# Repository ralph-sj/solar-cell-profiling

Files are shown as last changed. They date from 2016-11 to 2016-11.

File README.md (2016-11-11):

# solar-cell-profiling using a low power micro-computer
Hardware and software for power profiling a solar cell over a range of irradiances using cheap/easy to use hardware and software e.g. low power ADC/op-amps and raspberry pi/arduino 

## Introduction

A raspberry pi can be set up to measure voltages over time as a simple datalogger.  An ADC is connected to the IO pins of the pi and configured to take measurements and return the data to the Pi.  Data can then be sent to a remote server or stored locally or processed further.

## Guides
Mathworks [1] have a simple tutorial for setting this up with an LCD screen.	This uses the MCP3004 ADC [2] connected to the raspberry pi.

## Impedance
The input impedance of the ADC determines the current sunk by the ADC from the source which it is measuring.  When the input impedance is low compared to the output impedance of the source then there will be a voltage drop due to the ADC sinking current.  There are guides that show examples of this and address ways to counter it [3,4].	

## Hardware

The hardware used here is selected for ease of use and availability, including the procesor, sensors and other peripherals. It consists of: 
- MSP430G2553 Launchpad.  This is the demo board for the G2553 variant of the popular MSP430 MCU.
- LT1920 instrumentation amplifier.

### MCU
### Trans-Impedance Amplifier
This is used decrease the voltage drop imposed by the use of an ammeter in series within the monitoring circuit.  This allows a 1 Ohmm resistor to be used rather than the higher burden 1k.  As the currents measured here are typically low (uA - mA), to e.g. resolve a 1uA current without gain (i.e. to convert a 1uA current to 1mA - the maximum resolution of the 10-bit ADC used with a 1V reference) a 1K resistor would be needed.  This would then drop the voltage in the circuit by that amount.  By using a 1 Ohm resistor, that burden is reduced to an almost immeasurable 1 uA ^[11].  The burden voltage is 10µV/µA and 10µV/nA on the lower ranges and varies on the mA range due to the switch resistance.  

**Ranges:**

- Current ranges:
    1. +/- 0-300mA (70µV / mA burden voltage typical) - max 21mV
    2. +/- 0-1000µA (10µV / uA burden voltage) - max 10 mV
    3. +/- 0-1000nA (10µV / nA burden voltage) - max 10 mV
- Output Voltage Units:
    1. 1mV/mA - max 3V
    2. 1mV/µA - max 1V
    3. 1mV/nA - max 1V
- Effective gain 100 (I think)

### Instrumentation amplifier
The **LT2910** instrumentation amplifier is used to amplify the signal from the trans-impedance amplifier.  The gain is variable from 1 to 10,00 and is determined by the value of the gain resistor, RG, connected across pins 1-8.  The gain for a given value of RG is given by
G = 1 + 49.4/RG
i.e. for the following gain values:
Gain = 1000, RG = 49.4 Ohms
Gain = 100, RG = 499 Ohms
Gain = 10, RG = 5.489 kOhms

An alternative is the AD8428 ^[6] which has a fixed gain of 2000

## Software
Simpel software running on a low power procesosr is to be created to read sensors and then save data in a remote server. It is designed to run on  the MSP-EXP430G2 launchpad ^[7],[8],[10].  This is used due to their availability, ease of use and low power operation
 
### Development environment
The Arduino-like Energia ^[9] development environment was used here due to the ease of use and the widespread availability of libraries.

## References
[1](http://makerzone.mathworks.com/resources/build-a-digital-voltmeter-using-raspberry-pi/) Mathworks, "Build a Digital Voltmeter Using Raspberry Pi" (2005)
[2](https://cdn-shop.adafruit.com/datasheets/MCP3008.pdf), Microchip, MCP3004 Datasheet (2008)
[3](http://www.ti.com/lit/an/spna088/spna088.pdf)
[4](http://www.ti.com/lit/an/sbaa090/sbaa090.pdf)
[5](http://cds.linear.com/docs/en/datasheet/1920f.pdf), LT21920 Datasheet
[6](http://www.analog.com/media/en/technical-documentation/data-sheets/AD8428.PDF), AD8428
[7](http://www.ti.com/tool/MSP-EXP430G2), MSP-EXP430G2 homepage
[9](http://energia.nu/pin-maps/guide_msp430g2launchpad/), Energia for launchpad
[10](http://www.ti.com/lsds/ti/tools-software/launchpads/launchpads.page), TI Launchpad Homepage
[11](http://alternatezone.com/electronics/ucurrent/uCurrentArticle.pdf), uCurrent infor sheet

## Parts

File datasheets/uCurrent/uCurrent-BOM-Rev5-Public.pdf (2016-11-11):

ITEM # | Designator | Part Number | Manufacturer | Description | Supplier 1 | Supplier 1 Part#
1 U1, U4 | MAX4239AUT | Maxim | MAX4239AUT+T OPAMP SOT23-6 | MAX4239AUT+T-ND | 2
2 U2 | LMV321AS5X | TI | 296-9567-1-ND | 1
3 U3 | TI | Voltage Monitor 3.0V/2.7V, Active Low | 1
4 R1 | Y14870R01000B9R | Resistor 0.01ohm 0.1% 15ppm 2512 package | Y14870R01000B9R | 1
5 R5, R15 | 1K 0.05% 0603 10ppm | 2
6 R3, R13 | RG1608N-682-W-T1 | 6K8 0.05% 0603 10ppm | RG16N6.8KWTR-ND | 2
7 R11, R14 | 2K2 0.05% 0603 10ppm | RG16N2.2KWTR-ND | 2
8 R2 | RG1608N-103-W-T1 | 10K 0.05% 0603 10ppm | RG16N10.0KWTR-ND | 1
9 R9 | RNCF0805AKT10R0 | 10R 0.05% 0805 10ppm | RNCF0805AKT10R0-ND | 1
10 R6, R7 | Any | 100K 1% 0603 | 2
11 R4, R8,R10,R12 | Any | 270R 1% 0603 | 4
12 C1, C2 | Any | 100nF 0603 X7R Capacitor | 2
13 C3, C4 | Any | 10pF 0603 X7R capacitor | 2
14 SW1, SW2 | C&K | CKC5111-ND | 2
15 BT1 | 1060K | Keystone | 2032 Battery Holder SMD | 1060K-ND | 1
16 D1 | APTR3216SYCK | 1206 Reverse Mount Orange LED | 754-1174-2-ND | 1
17 | UB5 | UB5 Jiffy Box | H0205 | 1
19 | Black Binding Post 12mm Gold on Copper | 99cent Hobbies | 16-010 (306-H) | 2
20 | Red Binding Post 12mm Gold on Copper | 99cent Hobbies | 16-010 (306-H) | 2

uCurrent Rev 5 Parts List

Qty

Digikey
SOT23-5 Opamp | Digikey
TPS3809L30DBVR (http://www.digikey.com/product-detail/en/TPS3809L30DBVR/296-10917-2-ND/382242) | | Digikey | 296-10917-2-ND
| Vishay | Digikey
RG1608N-102-W-T1 (http://www.digikey.com/product-detail/en/RG1608N-102-W-T1/RG16N1.0KWTR-ND/600597) | Susumu | Digikey | RG16N1.0KWTR-ND
| Susumu (http://digikey.com/Suppliers/us/Susumu.page?lang=en) | Digikey
RG1608N-222-W-T1 (http://www.digikey.com/product-detail/en/RG1608N-222-W-T1/RG16N2.2KWTR-ND/600605) | Susumu | Digikey
| Susumu | Digikey
| Stackpole (http://digikey.com/Suppliers/us/Stackpole-Electronics.page?lang=en) | Digikey
| | Digikey
| | Digikey
| | Digikey
| | Digikey | 1276-2154-2-nd
L203011MS02Q or
L203011MS02QE

SW SLIDE DP3T 6VDC 4A PCB NO
COMMON | Digikey
| | Digikey
| Kingbright | Digikey
| Altronics | Altronics

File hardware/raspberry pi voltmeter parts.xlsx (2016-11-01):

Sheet: Sheet1
Part | type | more info | size | purpose | No. required | Price | supplier link | Supplier order code | Mnfctr | Mnfctr. part no. | Net cost | Homepage | Datasheet | Note | Order note
ADC | ADC with Integrated Oscillator, and Reference | 4 channel | 12 bit | solar cell IV monitoring | 5 | 1.88 | ebay (China) (http://www.ebay.co.uk/itm/ADS1015-12-bit-precision-analog-to-digital-converter-ADC-development-board-/191891529986) | - | TI | ADS1015 | 9.4 | http://www.ti.com/product/ads1015 | http://www.ti.com/lit/ds/symlink/ads1013.pdf | on board | Ordered 01/11/2016
ADC | ADC with Integrated Oscillator, and Reference | 4 channel | 16 bit | solar cell IV monitoring | 5 | 1.97 | ebay (China) (http://www.ebay.co.uk/itm/16Bit-I2C-ADS1115-Module-ADC-4-channel-Pro-Gain-Amplifier-for-Arduino-RPi-/272041590206) | - | TI | ADS1115 | 9.85 | http://www.ti.com/product/ads1115/description | http://www.ti.com/lit/ds/symlink/ads1115.pdf | on board | Ordered 01/11/2016
ADC | ADC with Integrated Oscillator, and Reference | 1 channel | 12 bit | solar cell IV monitoring | 5 |  | ebay (China) | - | TI | ADS1013 | 0 | http://www.ti.com/product/ads1013 | http://www.ti.com/lit/ds/symlink/ads1013.pdf | on board
ADC | ADC with Integrated Oscillator, and Reference | 1 channel | 16 bit | solar cell IV monitoring | 5 |  | ebay (China) | - | TI | ADS1113 | 0 | http://www.ti.com/product/ads1113 | http://www.ti.com/lit/ds/symlink/ads1115.pdf | on board
ADC | ADC with Integrated Oscillator, and Reference | 4 channel | 12 bit | solar cell IV monitoring | 1 |  | ebay (UK) | - | TI | ADS1015 | 0 | http://www.ti.com/product/ads1016 | http://www.ti.com/lit/ds/symlink/ads1013.pdf | on board
ADC | ADC with Integrated Oscillator, and Reference | 4 channel | 16 bit | solar cell IV monitoring | 1 | £4.59 | ebay (UK) (http://www.ebay.co.uk/itm/16-Bit-I2C-Analogue-to-Digital-Convertor-Pro-Gain-Amp-ADS1115-4-Ch-Flux-Workshop-/111833735071) | - | TI | ADS1115 | 4.59 | http://www.ti.com/product/ads1115/description | http://www.ti.com/lit/ds/symlink/ads1115.pdf | on board | Ordered 01/11/2016
ADC | ADC with Integrated Oscillator, and Reference | 1 channel | 12 bit | solar cell IV monitoring | 1 |  | ebay (UK) |  | TI | ADS1013 | 0 | http://www.ti.com/product/ads1213 | http://www.ti.com/lit/ds/symlink/ads1013.pdf | on board
ADC | ADC with Integrated Oscillator, and Reference | 1 channel | 16 bit | solar cell IV monitoring | 1 |  | ebay (UK) |  | TI | ADS1113 | 0 | http://www.ti.com/product/ads1313 | http://www.ti.com/lit/ds/symlink/ads1115.pdf | on board
ADC | ADC with Integrated Oscillator, and Reference | 4 channel | 12 bit | solar cell IV monitoring | 20 | 1.99 | farnell (http://uk.farnell.com/texas-instruments/ads1015idgst/adc-12bit-i2c-int-mux-10msop/dp/1778211) | 1778211 | TI | ADS1015 | 39.8 | http://www.ti.com/product/ads1017 | http://www.ti.com/lit/ds/symlink/ads1013.pdf | IC only | obtain thru uni.
ADC | ADC with Integrated Oscillator, and Reference | 4 channel | 16 bit | solar cell IV monitoring | 20 | 4.01 | farnell (http://uk.farnell.com/texas-instruments/ads1115idgst/ic-adc-16bit-860sps-lp-10msop/dp/1762981) | 1762981 | TI | ADS1115 | 80.2 | http://www.ti.com/product/ads1115/description | http://www.ti.com/lit/ds/symlink/ads1115.pdf | IC only | obtain thru uni.
ADC | ADC with Integrated Oscillator, and Reference | 1 channel | 12 bit | solar cell IV monitoring | 20 |  |  |  | TI | ADS1013 | 0 | http://www.ti.com/product/ads1413 | http://www.ti.com/lit/ds/symlink/ads1013.pdf | IC only
ADC | ADC with Integrated Oscillator, and Reference | 1 channel | 16 bit | solar cell IV monitoring | 20 |  |  |  | TI | ADS1113 | 0 | http://www.ti.com/product/ads1513 | http://www.ti.com/lit/ds/symlink/ads1115.pdf | IC only
Luxmeter | Ambient light sensor | I2C (photometric) | 16 bit | solar cell IV monitoring | 5 | 0.99 | ebay (China) (http://www.ebay.co.uk/itm/Digital-BH1750FVI-Light-intensity-Sensor-Module-For-AVR-Arduino-3V-5V-power-/272041588675) | - | TI | BH1750 | 4.95
Luxmeter | Ambient light sensor | I2C (photometric) | 16 bit | solar cell IV monitoring | 10 | 2.77 | farnell (http://uk.farnell.com/rohm/bh1750fvi-tr/ambient-light-sensor-i2c-wsof/dp/2421284?ost=BH1750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) | 2421284 | TI | BH1750FVI-TR | 27.7 |  | http://www.farnell.com/datasheets/1813320.pdf?_ga=1.41028002.1625180374.1477948619 | IC only | obtain thru uni.
ADC | 2 channel ADC, serial interface | 500 kSPS | 16bit | solar cell IV monitoring | 1 | 37.5 | Digikey (http://www.digikey.co.uk/product-detail/en/texas-instruments/ADS8361EVM/296-19922-ND/562127) | 296-19922-ND | TI | ADS8361EVM | 37.5 |  | http://www.ti.com/lit/ug/slau094a/slau094a.pdf | evaluation board | obtain thru uni.
ADC | 2 channel ADC, serial interface | 500 kSPS | 16bit | solar cell IV monitoring | 2 | 14.21 | farnell (http://uk.farnell.com/texas-instruments/ads8361idbqg4/16bit-adc-dual-smd-8361-ssop24/dp/1206879?ost=ADS8361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) | 1206879 | TI | ADS8361 | 28.42 |  | http://www.ti.com/lit/ds/symlink/ads8361.pdf | IC only | obtain thru uni.
ADC | ADC with Integrated Oscillator, and Reference | 4 channel | 16 bit | solar cell IV monitoring | 1 | 113 | Digikey (http://www.digikey.co.uk/product-detail/en/texas-instruments/ADS1115EVM-PDK/296-29102-ND/2231566) | 296-29102-ND | TI | ADS1115EVM-PDK | 113 |  | http://www.ti.com/lit/ug/sbau157b/sbau157b.pdf | eval board | obtain thru uni.
ADC | Delta Sigma ADC, 4 channel | I2C interface | 18 bit | solar cell IV monitoring | 2 | 11.67 | farnell (http://uk.farnell.com/microchip/mcp3424ev/evaluation-module-data-converter/dp/2066252) | 2066252 | Microchip | MCP3424EV | 23.34 | https://www.element14.com/community/docs/DOC-71298?_ga=1.87123480.1625180374.1477948619 | http://www.farnell.com/datasheets/1509497.pdf?_ga=1.87123480.1625180374.1477948619 | eval board | obtain thru uni.
ADC | PGA, on-board reference | I2C, USB interfaces | 16 bit | solar cell IV monitoring | 1 | 37.05 | farnell (http://uk.farnell.com/texas-instruments/ads1118evm/evaluation-module-data-converter/dp/1961723) | 1961723 | TI | ADS1118EVM | 37.05 | http://www.ti.com/tool/ads1118evm | http://www.ti.com/lit/ug/sbau184/sbau184.pdf | eval board | obtain thru uni.
ADC | PGA, on-board reference | I2C, USB interfaces | 16 bit | solar cell IV monitoring | 5 | 4.01 | farnell (http://uk.farnell.com/texas-instruments/ads1118idgsr/adc-16bit-temp-sensor-10msop/dp/1947871) | 1947871 | TI | ADS1118IDGSR | 20.05 |  | http://www.farnell.com/datasheets/2019067.pdf?_ga=1.12324404.1625180374.1477948619 | IC only | obtain thru uni.
ADC | Delta Sigma ADC, 4 channel | I2C interface | 18 bit | solar cell IV monitoring | 5 | 3.25 | farnell (http://uk.farnell.com/microchip/mcp3424-e-sl/adc-18bit-quad-channel-14soic/dp/1630424) | 1630424 | Microchip | MCP3424-E/SL | 16.25 |  | http://www.farnell.com/datasheets/630401.pdf?_ga=1.13329079.1625180374.1477948619 | IC only | obtain thru uni.

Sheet: Total cost
Total | Date
452.1 | 2016-11-01

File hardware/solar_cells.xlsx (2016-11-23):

Solar cell parts information
part number | manufacturer | details | dimensions (mm) |  |  | datasheet | user's guide
 |  |  | width | height | area
KXOB22-12X1L | IXYS | 22x7mm solar cell, Vmpp~500mV, impp~44.6 mA, Isc~50mA, Voc~630 mV, → Pmpp~22mW, FF~0.7 | 22 | 7 | 154 | http://ixapps.ixys.com/DataSheet/KXOB22-12X1L-DATA-SHEET-20130902-.pdf | http://ixapps.ixys.com/DataSheet/ixys_solar.pdf
KXOB22-04X3L | IXYS | 22x7mm solar cell, Vmpp~1.5V, impp~13.38mA, Isc~15mA, Voc~1.89 mV → Pmpp~20mW, FF~0.7 | 22 | 7 | 154 | http://ixapps.ixys.com/DataSheet/KXOB22-04X3L-DATA-SHEET-20130902-.pdf | http://ixapps.ixys.com/DataSheet/ixys_solar.pdf
SLMD121H9L | IXYS | Monocrystalline Solar Cell 201mW 5.67V | 62 | 21 | 1302 | http://ixapps.ixys.com/datasheet/SLMD121H09.pdf
AM-1456CA | Panasonic | Amorphous Solar Cell 2.4V (indoor) | 25 | 10 | 250 | http://media.digikey.com/pdf/Data%20Sheets/Sanyo%20Energy/Amorphous_Br.pdf | http://www.digikey.co.uk/en/product-highlight/p/panasonic/glass-type-solar-cells
AM-1417CA | Panasonic | Amorphous Solar Cell 18.75µW 2.4V (indoor) | 35 | 13.9 | 486.5 | http://media.digikey.com/pdf/Data%20Sheets/Sanyo%20Energy/Amorphous_Br.pdf | http://www.digikey.co.uk/en/product-highlight/p/panasonic/glass-type-solar-cells
AM-1815CA | Panasonic | Amorphous Solar Cell 126µW 4.9V (indoor) | 58.1 | 48.6 | 2823.66 | http://media.digikey.com/pdf/Data%20Sheets/Sanyo%20Energy/Amorphous_Br.pdf | http://www.digikey.co.uk/en/product-highlight/p/panasonic/glass-type-solar-cells
AM-1816CA | Panasonic | Amorphous Solar Cell 252µW 4.9V (indoor) | 96.7 | 56.7 | 5482.89 | http://media.digikey.com/pdf/Data%20Sheets/Sanyo%20Energy/Amorphous_Br.pdf | http://www.digikey.co.uk/en/product-highlight/p/panasonic/glass-type-solar-cells
AM-5610CAR | Panasonic | Amorphous Solar Cell, max power: 16.8mW, Voc= 5.1V (outdoor) | 25 | 20 | 500 | http://media.digikey.com/pdf/Data%20Sheets/Sanyo%20Energy/Amorphous_Br.pdf | http://www.digikey.co.uk/en/product-highlight/p/panasonic/glass-type-solar-cells
AM-5412CAR | Panasonic | Amorphous Solar Cell, Pmax= 87.6mW, Voc = 3.4V (outdoor) | 50.1 | 33.1 | 1658.31 | http://media.digikey.com/pdf/Data%20Sheets/Sanyo%20Energy/Amorphous_Br.pdf | http://www.digikey.co.uk/en/product-highlight/p/panasonic/glass-type-solar-cells
CBC-PV-01N | Cymbet | Amorphous Solar Cell, I@ Pmpp 201µA ,V@Pmpp= 800mV, Isc= 212µA, Voc=1.2V | 58.1 | 56.7 | 3294.27 | http://www.cymbet.com/pdfs/DS-72-24.pdf

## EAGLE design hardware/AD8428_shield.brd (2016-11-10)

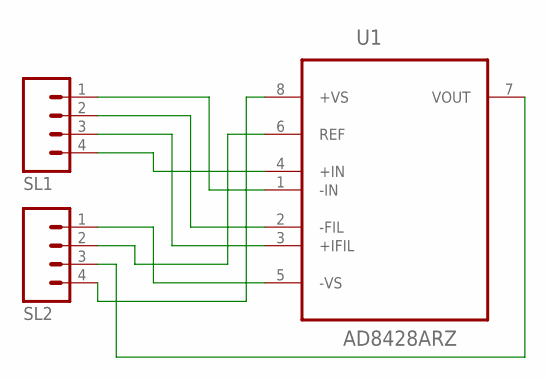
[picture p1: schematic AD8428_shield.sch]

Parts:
SL1, SL2: M04; 04P
U1: AD8428ARZ; SOIC127P600X175-8N

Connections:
unnamed: SL1.1, U1.1 (-IN)
unnamed: SL1.2, U1.2 (-FIL)
unnamed: SL1.3, U1.3 (+IFIL)
unnamed: SL1.4, U1.4 (+IN)
unnamed: SL2.1, U1.5 (-VS)
unnamed: SL2.2, U1.6 (REF)
unnamed: SL2.3, U1.7 (VOUT)
unnamed: SL2.4, U1.8 (+VS)

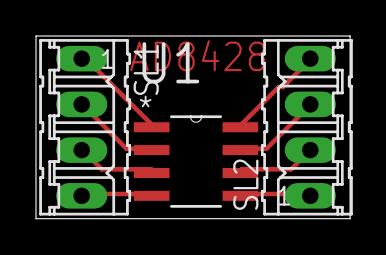
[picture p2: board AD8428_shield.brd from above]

Board: 2 copper layers, 17.4 x 10.2 mm, 3 parts (0 on the bottom side), 8 nets.

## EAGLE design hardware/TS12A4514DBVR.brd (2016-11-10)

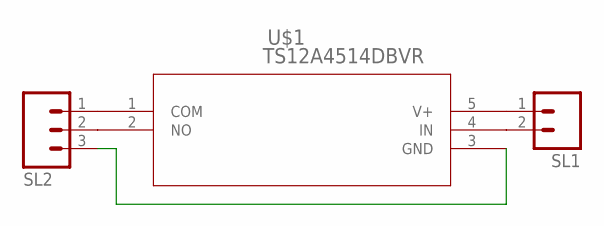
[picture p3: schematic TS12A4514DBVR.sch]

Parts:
SL1: M02; 02P
SL2: M03; 03P
U$1: TS12A4514DBVR; DBV5

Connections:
unnamed: SL1.1, U$1.5 (V+)
unnamed: SL1.2, U$1.4 (IN)
unnamed: SL2.1, U$1.1 (COM)
unnamed: SL2.2, U$1.2 (NO)
unnamed: SL2.3, U$1.3 (GND)

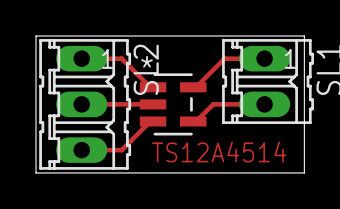
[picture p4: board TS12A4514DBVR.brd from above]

Board: 2 copper layers, 14.9 x 7.6 mm, 3 parts (0 on the bottom side), 5 nets.

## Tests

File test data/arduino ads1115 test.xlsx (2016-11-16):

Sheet: single-read
0 | 1
1 | 8
2 | 13
3 | 21
4 | 26
5 | 33
6 | 21
7 | 48
8 | 53
9 | 60
10 | 69
11 | 73
12 | 79
13 | 52
14 | 93
15 | 100
16 | 107
17 | 111
18 | 119
19 | 90
20 | 125
21 | 140
22 | 147
23 | 151
24 | 157
25 | 131
26 | 144
27 | 179
28 | 186
29 | 191
30 | 199
31 | 167
32 | 178
33 | 220
34 | 224
35 | 231
36 | 236
37 | 196
38 | 215
39 | 259
40 | 265
41 | 273
42 | 277
43 | 223
44 | 242
45 | 299
46 | 308
47 | 312
48 | 317
49 | 268
50 | 262
51 | 338
52 | 345
53 | 352
54 | 357
55 | 298
56 | 299
57 | 378
58 | 383
59 | 390
60 | 396
61 | 337
62 | 329
63 | 415
64 | 422
65 | 431
66 | 436
67 | 372
68 | 361
69 | 452
70 | 466
71 | 469
72 | 473
73 | 401
74 | 405
75 | 496
76 | 503
77 | 510
78 | 510
79 | 436
80 | 436
81 | 526
82 | 544
83 | 549
84 | 549
85 | 473
86 | 472
87 | 563
88 | 582
89 | 589
90 | 580
91 | 501
92 | 511
93 | 605
94 | 623
95 | 628
96 | 608
97 | 536
98 | 556
99 | 645
100 | 663
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

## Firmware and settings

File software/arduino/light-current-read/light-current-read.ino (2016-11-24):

#include <Wire.h>
#include <Adafruit_ADS1015.h>

 Adafruit_ADS1115 ads;  /* Use this for the 16-bit version */
// Adafruit_ADS1015 ads;     /* Use thi for the 12-bit version */

unsigned char bh1750_address = 35;

unsigned int current_gain = 0;

void setup(void)
{
  Serial.begin(9600);
  Serial.println("Hello!");

  Wire.begin();        // join i2c bus (address optional for master)
  
  Serial.println("Getting differential reading from AIN0 (P) and AIN1 (N)");
  //Serial.println("ADC Range:  +/- 1.024V  1 bit = 0.015625mV");
  
  // The ADC input range (or gain) can be changed via the following
  // functions, but be careful never to exceed VDD +0.3V max, or to
  // exceed the upper and lower limits if you adjust the input range!
  // Setting these values incorrectly may destroy your ADC!
  //                                                                ADS1015  ADS1115
  //                                                                -------  -------
   ads.setGain(GAIN_TWOTHIRDS);  // 2/3x gain +/- 6.144V  1 bit = 3mV      0.1875mV (default)
  // ads.setGain(GAIN_ONE);        // 1x gain   +/- 4.096V  1 bit = 2mV      0.125mV
  // ads.setGain(GAIN_TWO);        // 2x gain   +/- 2.048V  1 bit = 1mV      0.0625mV
  // ads.setGain(GAIN_FOUR);       // 4x gain   +/- 1.024V  1 bit = 0.5mV    0.03125mV
  // ads.setGain(GAIN_EIGHT);      // 8x gain   +/- 0.512V  1 bit = 0.25mV   0.015625mV
  // ads.setGain(GAIN_SIXTEEN);    // 16x gain  +/- 0.256V  1 bit = 0.125mV  0.0078125mV
  
  ads.begin();
}

void loop(void)
{
  
  Wire.beginTransmission(bh1750_address); // transmit to device #35 (0x23)
  Wire.write(byte(0x10));            // sends instruction byte  
  Wire.endTransmission();    // stop transmitting
  Wire.requestFrom(bh1750_address,2);    // request 2 bytes from slave device #2
  unsigned int light = 0;
  light = ((Wire.read()<<8) | (Wire.read())); // receive a byte as character
  Serial.print(light);
  Serial.print("," );

  int16_t results, results1;
  float multiplier;
  
  /* Be sure to update this value based on the IC and the gain settings! */
  // float   multiplier = 3.0F;    /* ADS1015 @ +/- 6.144V gain (12-bit results) */
  //float multiplier = 0.1875F; /* ADS1115  @ +/- 6.144V gain (16-bit results) */
  //  float   multiplier = 0.0078125F;    /* ADS1115 @ +/- 0.256V gain (16-bit results) */
  // float   multiplier = 0.015625F;    /* ADS1115 @ +/- 0.512V gain (16-bit results) */

  // read current
 switch (current_gain) {
    case 0:
      ads.setGain(GAIN_TWOTHIRDS);       // 2/3x gain +/- 6.144V  1 bit = 0.1875mV (default)
      multiplier = 0.1875F;    // 2/3x gain +/- 6.144V  1 bit = 0.1875mV (default)
      break;
    case 1:
      ads.setGain(GAIN_ONE);      // 1x gain   +/- 4.096V  1 bit = 0.125mV
      multiplier = 0.125F;      // 1x gain   +/- 4.096V  1 bit = 0.125mV
      break;
    case 2:
      ads.setGain(GAIN_TWO);      // 2x gain   +/- 2.048V  1 bit = 0.0625mV
      multiplier = 0.0625F;      // 2x gain   +/- 2.048V  1 bit = 0.0625mV
      break;
    case 4:
      ads.setGain(GAIN_FOUR);       // 4x gain   +/- 1.024V  1 bit = 0.03125mV
      multiplier = 0.03125F;  // 4x gain   +/- 1.024V  1 bit = 0.03125mV
      break;
    case 8:
      ads.setGain(GAIN_EIGHT);      // 8x gain   +/- 0.512V  1 bit = 0.015625mV
      multiplier = 0.015625F;    // 8x gain   +/- 0.512V  1 bit = 0.015625mV
      break;
    case 16:
      ads.setGain(GAIN_SIXTEEN);    // 16x gain  +/- 0.256V  1 bit = 0.0078125mV
      multiplier = 0.0078125F;    // 16x gain  +/- 0.256V  1 bit = 0.0078125mV
      break;
    default:
      ads.setGain(GAIN_TWOTHIRDS);       // 2/3x gain +/- 6.144V  1 bit = 0.1875mV (default)
      multiplier = 0.1875F;    // 2/3x gain +/- 6.144V  1 bit = 0.1875mV (default)
      break;
  }
  results = ads.readADC_Differential_0_1();  
  
  // Read voltage
  ads.setGain(GAIN_ONE);  
  float   multiplier1 = 0.125F;
  results1 = ads.readADC_Differential_2_3();  

    
  //Serial.print("Differential: "); Serial.print(results); Serial.print("("); Serial.print(results * multiplier); Serial.println("mV)");
  //Serial.println(results);
  Serial.print(results * multiplier); // current
  Serial.print(",");
  Serial.println(results1 * multiplier1); // voltage
  delay(1000);
}

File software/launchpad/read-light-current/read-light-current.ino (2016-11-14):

// Wire Master Reader
// by Nicholas Zambetti <http://www.zambetti.com>

// Demonstrates use of the Wire library
// Reads data from an I2C/TWI slave device
// Refer to the "Wire Slave Sender" example for use with this

// Created 29 March 2006

// This example code is in the public domain.


#include <Wire.h>
#define LED RED_LED
#define VCC 3572  // vcc in mV
#define ADC 3

unsigned char i2c_address = 35;

void setup()
{
    pinMode(LED, OUTPUT);     

  Wire.begin();        // join i2c bus (address optional for master)
  Serial.begin(9600);  // start serial for output
  Serial.print("Setup complete");
}

void loop()
{
  Wire.beginTransmission(i2c_address); // transmit to device #35 (0x23)
                              // device address is specified in datasheet
  Wire.write(byte(0x10));            // sends instruction byte  
  Wire.endTransmission();    // stop transmitting

  Wire.requestFrom(i2c_address,2);    // request 2 bytes from slave device #2

//  while(Wire.available())    // slave may send less than requested
//  { 
//    char c = Wire.read(); // receive a byte as character
//    Serial.print(c);         // print the character
//  }
    unsigned int light = 0;
    light = ((Wire.read()<<8) | (Wire.read())); // receive a byte as character
    Serial.print(light);
    Serial.print("," );
  unsigned long sensorValue = analogRead(A3);
  sensorValue = (sensorValue * VCC)>>10;
  Serial.println(sensorValue);

  // digitalWrite(LED, HIGH);   // turn the LED on (HIGH is the voltage level)
  delay(500);               // wait for a second
  digitalWrite(LED, LOW);    // turn the LED off by making the voltage LOW
  delay(500);               // wait for a second
}

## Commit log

2016-10-31 added parts spreadsheet
    [raspberry pi voltmeter parts.xlsx]
2016-11-01 hardware/software folders created
    pats spreadsheet moved
    # Please enter the commit message for your changes. Lines starting
    # with '#' will be ignored, and an empty message aborts the commit.
    # On branch master
    # Your branch is up-to-date with 'origin/master'.
    #
    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
    [raspberry pi voltmeter parts.xlsx]
2016-11-01 - updated parts list
    ordered components
    [raspberry pi voltmeter parts.xlsx]
2016-11-10 - added ADC and inst. amp shields
    added shields for AD8428 inst amp (set gain 2000) and ADS1015 12 bit ADC
    [AD8428_shield.brd, AD8428_shield.sch, ADS1015_shield.brd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]
2016-11-10 updated AD8428 shield
    - added text to board
    [AD8428_shield.brd, TS12A4514DBVR.brd, TS12A4514DBVR.sch]
2016-11-11 Added uCurrent files
    Added design/information files regarding uCurrent current amplifier circuit.
2016-11-11 Added software
    Added Launchpad Energia programme, read-light-current.ino to software folder
2016-11-14 created altium files
    converted eagle-altium file for AD8428 board
    [AD8428_shield.PcbDoc, AD8428_shield.PrjPcb, AD8428_shield.SchDoc]
2016-11-14 added altium PCBs
    converted ADS1015 board eagle-altium
    [ADS1015_shield.PcbDoc, ADS1015_shield.PrjPcb, ADS1015_shield.SchDoc]
2016-11-14 added altium PCB
    Converted TS12A4514 shield PCB eagle-altium
    [TS12A4514DBVR.PcbDoc, TS12A4514DBVR.PrjPcb, TS12A4514DBVR.SchDoc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]
2016-11-14 Created zip file for altium PCB
    - added all alitum PCB files to zip file for sending to mnfctr
2016-11-14 added ADS1x15 software
    - added adafruit ADS1x15 (arduino) library
    - added example code from (arduino) examples
2016-11-14 updated read-light-current
    - renamed address character
2016-11-15 added ADS1115 code arduino
    added arduino example code for reading 1 channel using adafruit library
2016-11-15 arduino test
    - added .ino file for testing Arduino
    - added test data for ADC calibration
    [arduino ads1115 test.xlsx]
2016-11-15 updated Arduino code
    - reconfigured for ADS1115
    - updated range of DAC for test
2016-11-15 updated ads1115 test data
    - added test with differential input, single-ended with potentiometer
    [arduino ads1115 test.xlsx]
2016-11-16 added test data
    added test data spreadsheets with initial power profiles of a selection of solar cells
    [solar-cell-profile-data-1.xlsx, solar-cell-profile-data.xlsx]
2016-11-16 reconfigured arduino code layout
    moved arduino code to new folder
    updated arduino software for running power profile
2016-11-21 updated arduino program
    changed gain settings for current and voltage
    changed initial splurge output
    input switch statement for setting current gain
    changed voltage rang to +/- 2V
    changed current range to +/i 0.256V (i.e. +/- 256 uA with middle uCurrent gain setting)
2016-11-22 Added support for changing gain of ADC
    gain can be selected as 2,4,8,16
2016-11-22 updated read_photo_current_with_title.m
    - changed to file selction by name c.f. full path
    - corrected current unit to uA and power units, uW, for graph labelling
    - added title to final graph with filename
2016-11-22 changed current gain
    set to 8 for AM-1417CA solar cell
2016-11-23 matlab files moved to analysis folder
    [solar-cell-profile-data-1.xlsx, solar-cell-profile-data.xlsx]
2016-11-23 matlabe files moved to analysis folder
    [solar-cell-profile-data-1.xlsx, solar-cell-profile-data.xlsx]
2016-11-23 added solar cell info spreadsheet
    spreadsheet contains summary of information on solar cell used (size, part no, datasheets)
    [solar_cells.xlsx]
2016-11-24 updated matlab figure plotter
    reformatted figures
    removed impedance plot
    added time/power plot
    added support for new (23/11/2016) solar cell (AM-5412CAR)
2016-11-24 updated bounds_test
    changed calculation of midpoints to midpoints of each data range c.f.
    average of all values
    included code to save summarised light and power light and power values
    to .mat files with the name of the file in the workspace
2016-11-24 added summarised data from solar cells
    .at files containing summarised power and light arrays for each solar
    cell in the format:
    l_av, p_av
    …, …
    generated from bounds_test.m
2016-11-24 updated matlab script and arduino code, added solar cell.xlsx

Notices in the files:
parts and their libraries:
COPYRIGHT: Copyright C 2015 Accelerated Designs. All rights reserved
